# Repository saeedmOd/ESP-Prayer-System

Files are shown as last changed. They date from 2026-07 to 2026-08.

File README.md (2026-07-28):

# 🕌 ESP Prayer System

An advanced ESP-based Islamic prayer system using ESP8266/ESP32 with DFPlayer audio playback, MQTT control, OTA updates, and prayer time management.

---
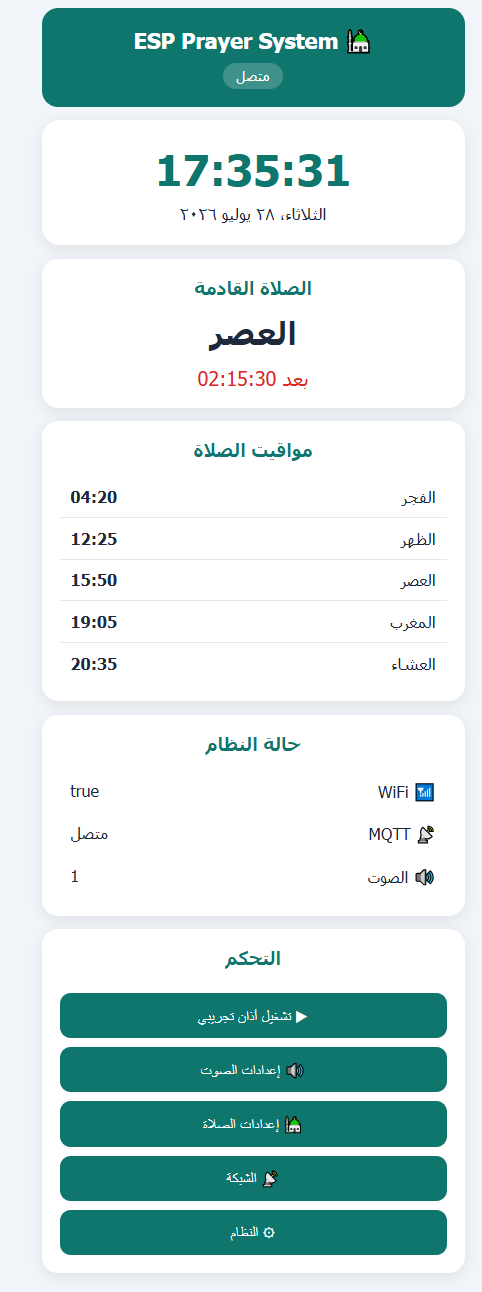
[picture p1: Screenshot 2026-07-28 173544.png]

# 📌 Project Overview

ESP Prayer System is a smart electronic device designed to:

- Calculate and manage prayer times.
- Play Azan automatically at prayer times.
- Control audio using DFPlayer Mini.
- Display prayer information on LCD/OLED screens.
- Support WiFi connectivity.
- Allow remote control using MQTT.
- Support OTA firmware updates.
- Store settings locally.

The system is designed with a modular software architecture using PlatformIO.

---

# ⚙️ Features

## 🕌 Prayer Management

- Automatic prayer time calculation.
- Next prayer countdown.
- Prayer schedule management.
- Support for different calculation methods.
- Daily prayer updates.

---

## 🔊 Audio System

Hardware:

- DFPlayer Mini MP3 Module
- Micro SD Card
- Amplifier (optional)

Supported audio:

The DFPlayer is controlled through UART communication.

---

# 📡 Connectivity

## WiFi

The system supports:

- WiFi connection.
- Automatic reconnect.
- Network status monitoring.

## MQTT

MQTT allows integration with:

- Home Assistant
- Node-RED
- Other IoT systems

Example:

---

# 🔄 OTA Update

The firmware supports Over-The-Air updates.

Advantages:

- No USB cable required.
- Update firmware remotely.
- Faster development.

Module:

---

# 📺 Display

Supported displays:

- OLED I2C
- LCD I2C

Information displayed:

- Current time
- Current date
- Next prayer
- Countdown timer
- System status

---

# 🏗️ Software Structure

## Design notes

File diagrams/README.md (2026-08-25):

# ESP Prayer System - Diagrams

## Overview

This folder contains system diagrams for the ESP Prayer System project, created using [Mermaid.js](https://mermaid.js.org/) syntax.

## Files

| File | Description |
|---|---|
| `block-diagram.md` | System architecture showing all components and their relationships |
| `system-flow.md` | Initialization flow, main loop, prayer detection, and menu state machine |
| `connection-map.md` | Complete wiring diagram, pin assignments, and power distribution |

## How to View

### Option 1: Mermaid Live Editor (Recommended)

1. Open [mermaid.live](https://mermaid.live)
2. Copy the code block from any `.md` file (between the ` ```mermaid ` and ` ``` ` markers)
3. Paste into the editor
4. The diagram will render automatically
5. Use the **Actions** menu to download as PNG, SVG, or PDF

### Option 2: VS Code

Install the **Mermaid Preview** extension:
1. Open VS Code Extensions (Ctrl+Shift+X)
2. Search for "Mermaid Preview"
3. Install the extension
4. Open any `.md` file
5. Click the preview icon (top-right corner)
6. Select "Mermaid" preview

### Option 3: GitHub/GitLab

These platforms render Mermaid diagrams natively in Markdown files. Simply push the files to your repository.

### Option 4: Command Line

```bash
# Install mermaid-cli
npm install -g @mermaid-js/mermaid-cli

# Generate PNG from mermaid file
mmdc -i block-diagram.md -o block-diagram.png
```

## Diagram Descriptions

### Block Diagram
Shows the complete system architecture:
- **ESP8266 NodeMCU** as the central controller
- Input devices (Rotary Encoder, Stop Button)
- Output devices (LCD, DFPlayer Mini, Speaker, Buzzer)
- Network services (WiFi, NTP, MQTT, OTA, Web Server)
- Software modules and their interactions

### System Flow
Four detailed flowcharts:
1. **Initialization Flow** - Step-by-step startup sequence
2. **Main Loop Flow** - Continuous operation cycle
3. **Prayer Detection Flow** - How prayer times trigger Azan/Iqama
4. **Rotary Menu State Machine** - UI navigation states

### Connection Map
Complete wiring reference:
- Visual wiring diagram with all connections
- Pin assignment table with GPIO mapping
- Power distribution diagram
- I2C bus and Software Serial details

## Component Summary

| Component | Interface | Pins Used |
|---|---|---|
| LCD 16x2 I2C | I2C | D1 (SCL), D2 (SDA) |
| DFPlayer Mini | UART (Software) | D5 (RX), D6 (TX) |
| Rotary Encoder | Digital | D7 (CLK), D8 (DT), D4 (SW) |
| Stop Button | Digital | D2 (shared with LCD SDA) |
| Buzzer | PWM | D3 |

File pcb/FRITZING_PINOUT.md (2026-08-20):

# ESP Prayer System - Quick Pinout Reference

## ESP8266 NodeMCU Pin Mapping

```
        ┌─────────────────────────────────────┐
        │           ESP8266 NodeMCU            │
        │                                      │
   3V3 ─┤ 3V3                          GND ├── GND
        │                                      │
   D0   ┤ GPIO16  (Not used)           A0   ├── ADC
        │                                      │
   D1   ┤ GPIO5   ──── LCD SCL               │
        │                                      │
   D2   ┤ GPIO4   ──── LCD SDA               │
        │              ──── Stop Button       │
        │                                      │
   D3   ┤ GPIO0   ──── Buzzer                │
        │                                      │
   D4   ┤ GPIO2   ──── Rotary SW             │
        │                                      │
   D5   ┤ GPIO14  ──── DFPlayer RX           │
        │                                      │
   D6   ┤ GPIO12  ──── DFPlayer TX           │
        │                                      │
   D7   ┤ GPIO13  ──── Rotary CLK            │
        │                                      │
   D8   ┤ GPIO15  ──── Rotary DT             │
        │                                      │
   RX   ┤ GPIO3   (Serial)           TX  ├── GPIO1
        │                                      │
        └─────────────────────────────────────┘
```

---

## Color Code

| Color | Purpose |
|---|---|
| 🔴 Red | Power (3V3, 5V) |
| ⚫ Black | Ground (GND) |
| 🔵 Blue | I2C Data (SDA) |
| 🟡 Yellow | I2C Clock (SCL) |
| 🟢 Green | Serial/UART |
| 🟠 Orange | Digital/Analog |
| 🟣 Purple | Control signals |

---

## Wire List (Copy-Paste Ready)

```
LCD I2C:
  VCC → 3V3
  GND → GND
  SDA → D2
  SCL → D1

DFPlayer Mini:
  VCC → 5V (or external)
  GND → GND
  RX  → D5 (via 1kΩ)
  TX  → D6

Rotary Encoder:
  VCC → 3V3
  GND → GND
  CLK → D7
  DT  → D8
  SW  → D4

Stop Button:
  Pin1 → D2
  Pin2 → GND

Buzzer:
  (+) → D3
  (-) → GND
```

---

## Quick ASCII Circuit

```
[USB/5V]───┐
           │
      ┌────┴────┐
      │ ESP8266 │
      │ NodeMCU │
      └────┬────┘
           │
    ┌──────┼──────┬──────────┬──────────┐
    │      │      │          │          │
┌───┴───┐ ┌┴────┐ ┌─────┐ ┌─┴───┐ ┌───┴───┐
│  LCD  │ │DFP  │ │ROTY │ │STOP │ │BUZZER │
│ 16x2  │ │Mini │ │Enc  │ │ BTN │ │       │
└───────┘ └─────┘ └─────┘ └─────┘ └───────┘
```

---

*For detailed wiring, see FRITZING_WIRING_GUIDE.md*

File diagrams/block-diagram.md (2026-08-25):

# ESP Prayer System - Block Diagram

```mermaid
graph TB
    subgraph "Power Supply"
        USB["USB / 5V Power"]
    end

    subgraph "ESP8266 NodeMCU"
        MCU["ESP8266<br/>NodeMCU"]
        CPU["CPU 80MHz<br/>RAM 80KB<br/>Flash 4MB"]
        WiFi_Mod["WiFi 2.4GHz<br/>802.11 b/g/n"]
        GPIO["GPIO Pins<br/>D0 - D8"]
    end

    subgraph "Input Devices"
        ROTARY["Rotary Encoder<br/>CLK=D7, DT=D8, SW=D4"]
        STOP["Stop Button<br/>D2"]
    end

    subgraph "Output Devices"
        LCD["LCD 16x2 I2C<br/>Address: 0x27<br/>SDA=D2, SCL=D1"]
        DFPlayer["DFPlayer Mini<br/>MP3 Module<br/>RX=D5, TX=D6"]
        SPEAKER["Speaker<br/>3W / 8Ohm"]
        BUZZER["Buzzer<br/>Active Piezo<br/>D3"]
    end

    subgraph "Network Services"
        NTP["NTP Client<br/>pool.ntp.org"]
        MQTT["MQTT Client<br/>PubSubClient"]
        OTA["OTA Updates<br/>ArduinoOTA"]
        WEB["Web Server<br/>AsyncWebServer<br/>Port 80"]
    end

    subgraph "Software Modules"
        STORAGE["Storage<br/>LittleFS<br/>config.json"]
        SETTINGS["Settings<br/>SystemSettings"]
        PRAYER["Prayer Engine<br/>6 Prayers<br/>8 Methods"]
        TIME["Time Manager<br/>NTP Sync"]
        MENU["Rotary Menu<br/>5 Modes"]
        DISPLAY_MOD["Display Manager<br/>LCD Driver"]
        CMD["Command Handler<br/>Serial/MQTT"]
    end

    subgraph "User Interface"
        BROWSER["Web Browser<br/>Dashboard"]
        LCD_UI["LCD Display<br/>Time + Prayer"]
        PHYSICAL["Physical Controls<br/>Rotary + Button"]
    end

    %% Power connections
    USB --> MCU

    %% MCU connections
    MCU --> CPU
    MCU --> WiFi_Mod
    MCU --> GPIO

    %% Input devices
    GPIO --> ROTARY
    GPIO --> STOP

    %% Output devices
    GPIO --> LCD
    GPIO --> DFPlayer
    DFPlayer --> SPEAKER
    GPIO --> BUZZER

    %% Network
    WiFi_Mod --> NTP
    WiFi_Mod --> MQTT
    WiFi_Mod --> OTA
    WiFi_Mod --> WEB

    %% Software modules
    MCU --> STORAGE
    MCU --> SETTINGS
    MCU --> PRAYER
    MCU --> TIME
    MCU --> MENU
    MCU --> DISPLAY_MOD
    MCU --> CMD

    %% User interfaces
    WEB --> BROWSER
    LCD --> LCD_UI
    ROTARY --> PHYSICAL
    STOP --> PHYSICAL

    %% Data flow
    TIME --> PRAYER
    PRAYER --> DISPLAY_MOD
    PRAYER --> DFPlayer
    PRAYER --> BUZZER
    SETTINGS --> PRAYER
    SETTINGS --> DISPLAY_MOD
    STORAGE --> SETTINGS
    MENU --> DISPLAY_MOD
    CMD --> PRAYER

    %% Styling
    classDef mcu fill:#e1f5fe,stroke:#0288d1,stroke-width:3px
    classDef input fill:#fff3e0,stroke:#f57c00,stroke-width:2px
    classDef output fill:#e8f5e9,stroke:#388e3c,stroke-width:2px
    classDef network fill:#f3e5f5,stroke:#7b1fa2,stroke-width:2px
    classDef software fill:#fce4ec,stroke:#c62828,stroke-width:2px
    classDef ui fill:#e0f2f1,stroke:#00695c,stroke-width:2px
    classDef power fill:#fffde7,stroke:#f9a825,stroke-width:2px

    class MCU,CPU,WiFi_Mod,GPIO mcu
    class ROTARY,STOP input
    class LCD,DFPlayer,SPEAKER,BUZZER output
    class NTP,MQTT,OTA,WEB network
    class STORAGE,SETTINGS,PRAYER,TIME,MENU,DISPLAY_MOD,CMD software
    class BROWSER,LCD_UI,PHYSICAL ui
    class USB power
```

---

## Legend

| Color | Category |
|---|---|
| 🔵 Blue | ESP8266 MCU (Central Controller) |
| 🟠 Orange | Input Devices |
| 🟢 Green | Output Devices |
| 🟣 Purple | Network Services |
| 🔴 Red | Software Modules |
| 🟤 Teal | User Interfaces |
| 🟡 Yellow | Power Supply |

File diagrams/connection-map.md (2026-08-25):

# ESP Prayer System - Connection Map

## 1. Complete Wiring Diagram

```mermaid
graph LR
    subgraph "ESP8266 NodeMCU"
        D0["D0<br/>GPIO16"]
        D1["D1<br/>GPIO5"]
        D2["D2<br/>GPIO4"]
        D3["D3<br/>GPIO0"]
        D4["D4<br/>GPIO2"]
        D5["D5<br/>GPIO14"]
        D6["D6<br/>GPIO12"]
        D7["D7<br/>GPIO13"]
        D8["D8<br/>GPIO15"]
        VCC["3V3"]
        GND1["GND"]
        VIN["VIN/5V"]
        GND2["GND"]
    end

    subgraph "LCD 16x2 I2C"
        LCD_VCC["VCC"]
        LCD_GND["GND"]
        LCD_SDA["SDA"]
        LCD_SCL["SCL"]
    end

    subgraph "DFPlayer Mini"
        DFP_VCC["VCC"]
        DFP_GND["GND"]
        DFP_RX["RX"]
        DFP_TX["TX"]
        DFP_SPK1["SPK_1"]
        DFP_SPK2["SPK_2"]
    end

    subgraph "Rotary Encoder"
        ROT_VCC["VCC"]
        ROT_GND["GND"]
        ROT_CLK["CLK"]
        ROT_DT["DT"]
        ROT_SW["SW"]
    end

    subgraph "Stop Button"
        BTN_1["Pin 1"]
        BTN_2["Pin 2"]
    end

    subgraph "Buzzer"
        BUZ_PLUS["+"]
        BUZ_MINUS["-"]
    end

    subgraph "Speaker"
        SPK_1["+"]
        SPK_2["-"]
    end

    %% LCD Connections
    D1 -->|"SCL"| LCD_SCL
    D2 -->|"SDA"| LCD_SDA
    VCC --> LCD_VCC
    GND1 --> LCD_GND

    %% DFPlayer Connections
    D5 -->|"RX (via 1kΩ)"| DFP_RX
    D6 -->|"TX"| DFP_TX
    VIN --> DFP_VCC
    GND2 --> DFP_GND
    DFP_SPK1 --> SPK_1
    DFP_SPK2 --> SPK_2

    %% Rotary Encoder Connections
    D7 --> ROT_CLK
    D8 --> ROT_DT
    D4 --> ROT_SW
    VCC --> ROT_VCC
    GND1 --> ROT_GND

    %% Stop Button
    D2 --> BTN_1
    GND1 --> BTN_2

    %% Buzzer
    D3 --> BUZ_PLUS
    GND1 --> BUZ_MINUS

    style D1 fill:#4caf50,color:#fff
    style D2 fill:#4caf50,color:#fff
    style D3 fill:#ff5722,color:#fff
    style D4 fill:#ff9800,color:#fff
    style D5 fill:#2196f3,color:#fff
    style D6 fill:#2196f3,color:#fff
    style D7 fill:#ff9800,color:#fff
    style D8 fill:#ff9800,color:#fff
```

## 2. Pin Assignment Table

| Pin | GPIO | Component | Function | Wire Color |
|-----|---|---|---|---|
| D0 | GPIO16 | - | Not Used | - |
| **D1** | GPIO5 | LCD 16x2 | I2C SCL | 🟡 Yellow |
| **D2** | GPIO4 | LCD 16x2 | I2C SDA | 🔵 Blue |
| **D2** | GPIO4 | Stop Button | Digital Input | 🟣 Purple |
| **D3** | GPIO0 | Buzzer | PWM Output | 🟠 Orange |
| **D4** | GPIO2 | Rotary Encoder | SW (Button) | 🟠 Orange |
| **D5** | GPIO14 | DFPlayer Mini | RX (via 1kΩ) | 🟢 Green |
| **D6** | GPIO12 | DFPlayer Mini | TX | 🟢 Green |
| **D7** | GPIO13 | Rotary Encoder | CLK | 🟠 Orange |
| **D8** | GPIO15 | Rotary Encoder | DT | 🟠 Orange |
| RX | GPIO3 | Serial Monitor | Debug Output | - |
| TX | GPIO1 | Serial Monitor | Debug Input | - |
| 3V3 | - | LCD, Rotary | Power (3.3V) | 🔴 Red |
| VIN | - | DFPlayer | Power (5V) | 🔴 Red |
| GND | - | All Components | Ground | ⚫ Black |

## 3. Power Distribution

```mermaid
graph TD
    USB["USB / 5V Source"] --> VIN["VIN Pin<br/>5V"]

    VIN --> DFP_PWR["DFPlayer Mini<br/>VCC (5V)"]
    VIN --> REG["3.3V Regulator<br/>(On-board)"]

    REG --> VCC33["3V3 Pin<br/>3.3V"]
    VCC33 --> LCD_PWR["LCD 16x2<br/>VCC"]
    VCC33 --> ROT_PWR["Rotary Encoder<br/>VCC"]

    USB --> GND_BUS["Common Ground"]
    GND_BUS --> DFP_GND["DFPlayer<br/>GND"]
    GND_BUS --> LCD_GND["LCD<br/>GND"]
    GND_BUS --> ROT_GND["Rotary<br/>GND"]
    GND_BUS --> BTN_GND["Stop Button<br/>GND"]
    GND_BUS --> BUZ_GND["Buzzer<br/>GND"]

    style USB fill:#ff9800,color:#fff
    style REG fill:#4caf50,color:#fff
    style GND_BUS fill:#333,color:#fff
```

## 4. I2C Bus

```mermaid
graph LR
    SDA["SDA Bus<br/>GPIO4 / D2"] --> LCD["LCD 16x2<br/>Address: 0x27"]
    SCL["SCL Bus<br/>GPIO5 / D1"] --> LCD

    style SDA fill:#2196f3,color:#fff
    style SCL fill:#ffc107,color:#000
```

## 5. Software Serial (DFPlayer)

```mermaid
graph LR
    ESP_TX["ESP TX<br/>GPIO14 / D5"] -->|"via 1kΩ"| DFP_RX["DFPlayer RX"]
    DFP_TX["DFPlayer TX"] --> ESP_RX["ESP RX<br/>GPIO12 / D6"]

    style ESP_TX fill:#4caf50,color:#fff
    style DFP_RX fill:#2196f3,color:#fff
    style DFP_TX fill:#2196f3,color:#fff
    style ESP_RX fill:#4caf50,color:#fff

    note1["Baud Rate: 9600"]
    note2["Voltage: 3.3V Logic"]
```

---

## Quick Reference

```
┌─────────────────────────────────────────────────┐
│              ESP8266 NodeMCU                    │
│                                                 │
│  3V3 ──┬──┬────────────────────── GND ──┬──┬──  │
│        │  │                             │  │    │
│  D0    │  │ (Not Used)            A0    │  │    │
│        │  │                             │  │    │
│  D1 ───┼──┼──── LCD SCL                 │  │    │
│        │  │                             │  │    │
│  D2 ───┼──┼──── LCD SDA                 │  │    │
│        │  │     Stop Button             │  │    │
│        │  │                             │  │    │
│  D3 ───┼──┼──── Buzzer (+)              │  │    │
│        │  │                             │  │    │
│  D4 ───┼──┼──── Rotary SW               │  │    │
│        │  │                             │  │    │
│  D5 ───┼──┼──── DFPlayer RX (1kΩ)       │  │    │
│        │  │                             │  │    │
│  D6 ───┼──┼──── DFPlayer TX             │  │    │
│        │  │                             │  │    │
│  D7 ───┼──┼──── Rotary CLK              │  │    │
│        │  │                             │  │    │
│  D8 ───┼──┼──── Rotary DT               │  │    │
│        │  │                             │  │    │
│  RX    │  │ (Serial Debug)         TX   │  │    │
│        │  │                             │  │    │
└────────┴──┴─────────────────────────────┴──┴──┘
         │  │                             │  │
         │  └──── 3.3V Power ────────────┘  │
         └──── 5V (VIN) ────────────────────┘
```

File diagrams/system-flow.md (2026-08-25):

# ESP Prayer System - System Flow Diagram

## 1. Initialization Flow (setup)

```mermaid
flowchart TD
    START["🔌 Power On / Reset"] --> SERIAL["Initialize Serial<br/>115200 baud"]
    SERIAL --> VERSION["Print Version Info<br/>v1.0.0"]
    VERSION --> STORAGE["Mount LittleFS<br/>Load config.json"]
    STORAGE --> SETTINGS["Load Settings<br/>Validate & Clamp"]
    SETTINGS --> WIFI{"WiFi Connected?"}

    WIFI -->|"Yes (STA Mode)"| IP["Get IP Address"]
    WIFI -->|"No / Timeout"| AP["Start AP Mode<br/>ESP-Prayer-Setup<br/>192.168.4.1"]

    IP --> WEB["Start Web Server<br/>Port 80"]
    AP --> WEB

    WEB --> NET_CHECK{"WiFi Connected?"}

    NET_CHECK -->|"Yes"| NET_INIT["Initialize Network Services"]
    NET_CHECK -->|"No"| HW_INIT

    NET_INIT --> OTA["OTA Ready<br/>ArduinoOTA"]
    OTA --> NTP["NTP Sync<br/>pool.ntp.org"]
    NTP --> TIME_OK{"Time Synced?"}

    TIME_OK -->|"Yes"| MQTT["MQTT Init<br/>Connect Broker"]
    TIME_OK -->|"No"| HW_INIT

    MQTT --> DFP["DFPlayer Init<br/>9600 baud"]
    DFP --> PRAYER["Prayer Init<br/>Calculate Times"]
    PRAYER --> DISP["Display Init<br/>LCD 16x2"]
    DISP --> MARK["Mark Network<br/>Services Ready"]

    MARK --> HW_INIT["Hardware Init<br/>Buzzer + Rotary"]
    HW_INIT --> TONE["Play Startup Tone"]
    TONE --> WIFI_TONE{"WiFi Connected?"}
    WIFI_TONE -->|"Yes"| CONN_TONE["Play WiFi Connected Tone"]
    WIFI_TONE -->|"No"| MENU_INIT
    CONN_TONE --> MENU_INIT["Rotary Menu Init"]
    MENU_INIT --> READY["✅ System Ready"]

    style START fill:#ff9800,color:#fff
    style READY fill:#4caf50,color:#fff
    style WIFI fill:#2196f3,color:#fff
    style NET_CHECK fill:#2196f3,color:#fff
    style TIME_OK fill:#2196f3,color:#fff
    style WIFI_TONE fill:#2196f3,color:#fff
```

## 2. Main Loop Flow

```mermaid
flowchart TD
    LOOP["🔄 Main Loop Start"] --> HW["hardware_loop()<br/>Read Encoder + Button<br/>Update Buzzer Tones"]
    HW --> WIFI_L["wifi_loop()<br/>Monitor Connection<br/>Reconnect if Needed"]

    WIFI_L --> WIFI_OK{"WiFi Connected?"}

    WIFI_OK -->|"Yes"| NET_CHECK{"Network<br/>Initialized?"}
    WIFI_OK -->|"No"| PRAYER_L

    NET_CHECK -->|"Yes"| OTA_H["OTA.handle()<br/>Process Updates"]
    NET_CHECK -->|"No"| TRY_INIT["Try Initialize<br/>Network Services"]

    OTA_H --> MQTT_L["mqtt_loop()<br/>Process Messages"]
    MQTT_L --> TIME_U["time_update()<br/>Refresh NTP Time"]

    TRY_INIT --> PRAYER_L
    TIME_U --> PRAYER_L

    PRAYER_L["prayer_loop()<br/>Check Prayer Times<br/>Trigger Azan/Iqama"]

    PRAYER_L --> MENU_L{"Network<br/>Initialized?"}
    MENU_L -->|"Yes"| RMENU["rotary_menu_loop()<br/>Process Input<br/>Update Display"]
    MENU_L -->|"No"| WEB_L

    RMENU --> WEB_L["web_server_loop()<br/>Handle HTTP Requests"]
    WEB_L --> LOOP

    style LOOP fill:#ff9800,color:#fff
    style WIFI_OK fill:#2196f3,color:#fff
    style NET_CHECK fill:#2196f3,color:#fff
    style MENU_L fill:#2196f3,color:#fff
```

## 3. Prayer Time Detection Flow

```mermaid
flowchart TD
    CHECK["prayer_loop()"] --> TIME{"Time Changed?"}

    TIME -->|"No"| SKIP["Skip"]
    TIME -->|"Yes"| DAY{"New Day?"}

    DAY -->|"Yes"| RECALC["Recalculate<br/>All Prayer Times"]
    DAY -->|"No"| FAJR{"Fajr Time?"}

    RECALC --> FAJR

    FAJR -->|"Yes & Not Played"| PLAY_AZAN_F["Play Azan<br/>Fajr"]
    FAJR -->|"No"| DHUHR{"Dhuhr Time?"}

    PLAY_AZAN_F --> IQAMA_F{"Iqama<br/>Delay Done?"}
    IQAMA_F -->|"Yes"| PLAY_IQAMA_F["Play Iqama<br/>Fajr"]

    DHUHR -->|"Yes & Not Played"| PLAY_AZAN_D["Play Azan<br/>Dhuhr"]
    DHUHR -->|"No"| ASR{"Asr Time?"}

    PLAY_AZAN_D --> IQAMA_D{"Iqama<br/>Delay Done?"}
    IQAMA_D -->|"Yes"| PLAY_IQAMA_D["Play Iqama<br/>Dhuhr"]

    ASR -->|"Yes & Not Played"| PLAY_AZAN_A["Play Azan<br/>Asr"]
    ASR -->|"No"| MAGHRIB{"Maghrib Time?"}

    PLAY_AZAN_A --> IQAMA_A{"Iqama<br/>Delay Done?"}
    IQAMA_A -->|"Yes"| PLAY_IQAMA_A["Play Iqama<br/>Asr"]

    MAGHRIB -->|"Yes & Not Played"| PLAY_AZAN_M["Play Azan<br/>Maghrib"]
    MAGHRIB -->|"No"| ISHA{"Isha Time?"}

    PLAY_AZAN_M --> IQAMA_M{"Iqama<br/>Delay Done?"}
    IQAMA_M -->|"Yes"| PLAY_IQAMA_M["Play Iqama<br/>Maghrib"]

    ISHA -->|"Yes & Not Played"| PLAY_AZAN_I["Play Azan<br/>Isha"]
    ISHA -->|"No"| ADHKAR

    PLAY_AZAN_I --> IQAMA_I{"Iqama<br/>Delay Done?"}
    IQAMA_I -->|"Yes"| PLAY_IQAMA_I["Play Iqama<br/>Isha"]

    ADHKAR["Check Adhkar<br/>(Morning/Evening)"] --> KAHF{"Friday?<br/>Al-Kahf Time?"}
    KAHF -->|"Yes"| PLAY_KAHF["Play Surah<br/>Al-Kahf"]
    KAHF -->|"No"| CUSTOM{"Custom Alert<br/>Time?"}
    CUSTOM -->|"Yes"| PLAY_CUSTOM["Play Custom<br/>Alert"]
    CUSTOM -->|"No"| SKIP

    PLAY_IQAMA_F --> SKIP
    PLAY_IQAMA_D --> SKIP
    PLAY_IQAMA_A --> SKIP
    PLAY_IQAMA_M --> SKIP
    PLAY_IQAMA_I --> SKIP
    PLAY_KAHF --> SKIP
    PLAY_CUSTOM --> SKIP

    style CHECK fill:#ff9800,color:#fff
    style TIME fill:#2196f3,color:#fff
    style DAY fill:#2196f3,color:#fff
```

## 4. Rotary Menu State Machine

```mermaid
stateDiagram-v2
    [*] --> MODE_CLOCK: Init

    MODE_CLOCK --> MODE_MENU: Long Press
    MODE_CLOCK --> MODE_CLOCK: Short Press (Mute/Unmute)
    MODE_CLOCK --> MODE_CLOCK: Rotate (Volume +/-)

    MODE_MENU --> MODE_PRAYERS: Select "Prayer Times"
    MODE_MENU --> MODE_VOLUME: Select "Volume"
    MODE_MENU --> MODE_BRIGHTNESS: Select "Brightness"
    MODE_MENU --> MODE_CLOCK: Back (Long Press)

    MODE_PRAYERS --> MODE_CLOCK: Back
    MODE_PRAYERS --> MODE_PRAYERS: Browse (Rotate)

    MODE_VOLUME --> MODE_CLOCK: Back
    MODE_VOLUME --> MODE_VOLUME: Adjust (Rotate)

    MODE_BRIGHTNESS --> MODE_CLOCK: Back
    MODE_BRIGHTNESS --> MODE_BRIGHTNESS: Toggle (Press)

    note right of MODE_CLOCK
        Default Mode
        Shows: Time + Next Prayer
        Rotary: Volume Control
        Press: Mute/Unmute
    end note
```

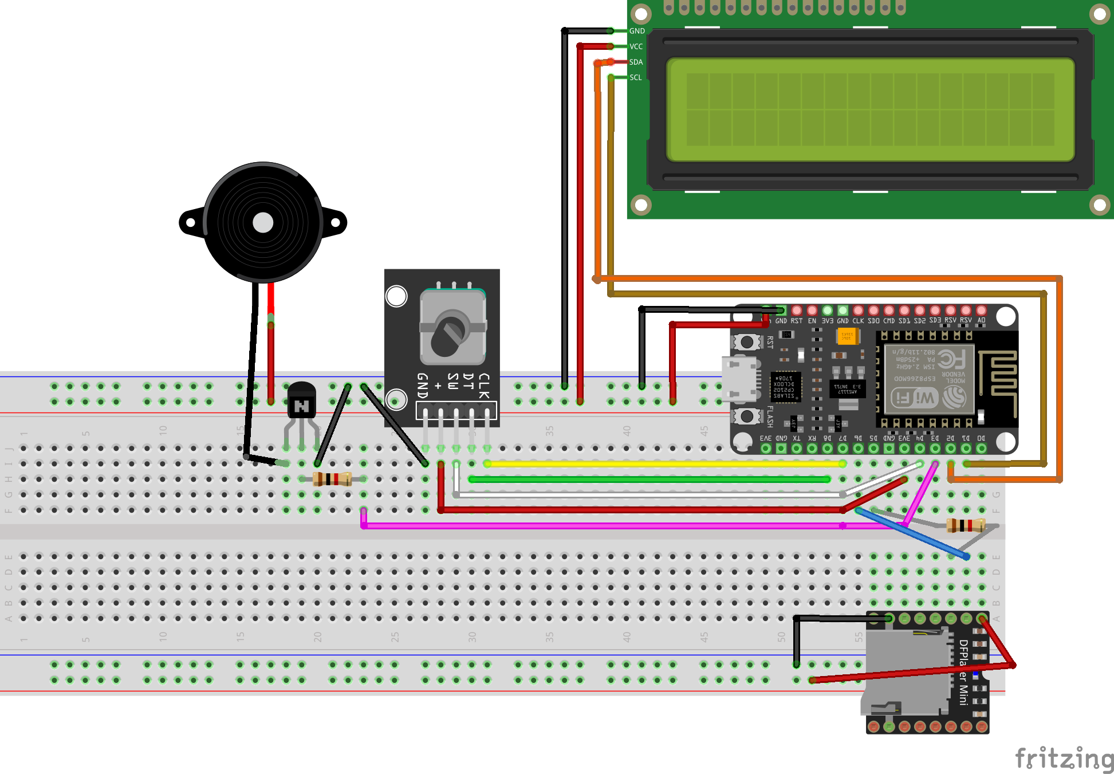
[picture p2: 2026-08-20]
pcb/ESP-Prayer-System_bb.png

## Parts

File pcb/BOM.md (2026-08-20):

# ESP Prayer System - Bill of Materials (BOM)

## Required Components

| #  | Reference | Component | Value/Package | Qty | Notes |
|----|---|---|---|-----|---|
| 1  | U1 | ESP8266 NodeMCU | 12-pin headers | 1 | V3 or Lite version |
| 2  | LCD1 | LCD 16x2 I2C Module | 0x27 address | 1 | With I2C backpack |
| 3  | DF1 | DFPlayer Mini | MP3 Module | 1 | With micro SD card slot |
| 4  | ENC1 | Rotary Encoder | KY-040 | 1 | With push button |
| 5  | SW1 | Stop Button | 6x6mm tactile | 1 | Normally Open |
| 6  | BZ1 | Active Buzzer | 5V, 5mm | 1 | Self-driving type |
| 7  | Q1 | NPN Transistor | 2N2222/S8050 | 1 | TO-92 package |
| 8  | R1 | Resistor | 1kΩ, 1/4W | 1 | Base resistor for transistor |
| 9  | R2 | Resistor | 1kΩ, 1/4W | 1 | DFPlayer RX line protection |

## Passive Components

| #  | Reference | Component | Value | Package | Qty | Notes |
|----|---|---|---|---|-----|---|
| 10 | C1 | Ceramic Capacitor| 100nF | 0805 | 1 | DFPlayer power filter  |
| 11 | C2 | Electrolytic Cap  | 100µF/10V | Radial  | 1 | Main power filter |
| 12 | C3 | Ceramic Capacitor| 100nF | 0805 | 1 | Rotary encoder debounce|

## Connectors

| #  | Reference  | Component | Pins | Qty | Notes |
|----|---|---|---|-----|---|
| 13 | J1 | USB Micro/B Type-B  | - | 1 | Power input (on NodeMCU) |
| 14 | J2 | Pin Header 2.54mm | 4pin | 1 | LCD I2C connection |
| 15 | J3 | Pin Header 2.54mm | 4pin | 1 | DFPlayer connection |
| 16 | J4 | Pin Header 2.54mm | 5pin | 1 | Rotary Encoder |
| 17 | J5 | Pin Header 2.54mm | 2pin | 1 | Stop Button |
| 18 | J6 | Pin Header 2.54mm | 2pin | 1 | Buzzer |
| 19 | J7 | Screw Terminal 3.5mm| 2pin | 1 | Speaker output (optional)|

## Optional Components

| #  | Reference | Component | Value | Qty | Notes |
|----|---|---|---|-----|---|
| 20 | LED1 | LED | Green | 1 | Power indicator |
| 21 | R3 | Resistor | 470Ω | 1 | LED current limiter |
| 22 | C4 | Ceramic Capacitor | 10µF | 1 | Optional power filtering |

## Mechanical

| #  | Component | Specification | Qty | Notes |
|----|---|---|-----|---|
| 23 | PCB | 80x50mm, 2L | 1 | FR4, 1.6mm thick |
| 24 | Mounting Hardware| M3 screws | 4 | For enclosure |
| 25 | Rubber Feet | 8mm diameter  | 4 | Non-slip |

---

## Source Links (Examples)

| Component | Search Term |
|---|---|
| ESP8266 | "NodeMCU ESP8266 V3" |
| LCD I2C | "LCD 1602 I2C 0x27" |
| DFPlayer Mini | "DFPlayer Mini MP3 Module" |
| Rotary Encoder  | "KY-040 Rotary Encoder" |
| Active Buzzer | "Active Buzzer 5V 5mm" |
| 2N2222 | "2N2222 NPN Transistor" |
| 1kΩ Resistors | "1kohm 1/4W Resistor Pack" |
| 100nF Caps | "100nF 0805 Capacitor Pack"  |
| 100µF Cap | "100uF 10V Electrolytic" |

---

## Estimated Cost

| Category | Estimated Cost (USD) |
|---|---|
| ESP8266 | $3 - $5 |
| LCD I2C | $2 - $3 |
| DFPlayer Mini  | $2 - $4 |
| Rotary Encoder | $1 - $2 |
| Passive Parts  | $1 - $2 |
| Connectors | $1 - $2 |
| PCB (5 pcs) | $5 - $10 |
| **Total** | **$15 - $28** |

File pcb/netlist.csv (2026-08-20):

Component | Reference | Pin | Net
ESP8266 NodeMCU | U1 | D0/GPIO16 | STOP_BTN
ESP8266 NodeMCU | U1 | D1/GPIO5 | LCD_SCL
ESP8266 NodeMCU | U1 | D2/GPIO4 | LCD_SDA
ESP8266 NodeMCU | U1 | D3/GPIO0 | BUZZER_DRIVE
ESP8266 NodeMCU | U1 | D4/GPIO2 | ROTARY_SW
ESP8266 NodeMCU | U1 | D5/GPIO14 | DFPLAYER_TX
ESP8266 NodeMCU | U1 | D6/GPIO12 | DFPLAYER_RX
ESP8266 NodeMCU | U1 | D7/GPIO13 | ROTARY_CLK
ESP8266 NodeMCU | U1 | D8/GPIO15 | ROTARY_DT
ESP8266 NodeMCU | U1 | 3V3 | +3V3
ESP8266 NodeMCU | U1 | GND | GND
ESP8266 NodeMCU | U1 | VIN | +5V
LCD 16x2 I2C | LCD1 | GND | GND
LCD 16x2 I2C | LCD1 | VCC | +5V
LCD 16x2 I2C | LCD1 | SDA | LCD_SDA
LCD 16x2 I2C | LCD1 | SCL | LCD_SCL
DFPlayer Mini | DF1 | VCC | +5V
DFPlayer Mini | DF1 | GND | GND
DFPlayer Mini | DF1 | RX | DFPLAYER_RX
DFPlayer Mini | DF1 | TX | DFPLAYER_TX
DFPlayer Mini | DF1 | SP+ | SPK_P
DFPlayer Mini | DF1 | SP- | SPK_N
Rotary Encoder | ENC1 | CLK | ROTARY_CLK
Rotary Encoder | ENC1 | DT | ROTARY_DT
Rotary Encoder | ENC1 | SW | ROTARY_SW
Rotary Encoder | ENC1 | + | +3V3
Rotary Encoder | ENC1 | - | GND
Stop Button | SW1 | Pin1 | STOP_BTN
Stop Button | SW1 | Pin2 | GND
Resistor | R1 | Pin1 | BUZZER_DRIVE
Resistor | R1 | Pin2 | Q1_BASE
NPN Transistor | Q1 | Base | Q1_BASE
NPN Transistor | Q1 | Collector | BUZZER_COL
NPN Transistor | Q1 | Emitter | GND
Active Buzzer | BZ1 | Pin1 | +5V
Active Buzzer | BZ1 | Pin2 | BUZZER_COL
Capacitor | C1 | Pin1 | +5V
Capacitor | C1 | Pin2 | GND
Capacitor | C2 | Pin1 | +5V
Capacitor | C2 | Pin2 | GND

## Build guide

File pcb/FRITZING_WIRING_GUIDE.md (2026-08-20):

# ESP Prayer System - Fritzing Wiring Guide

## Overview

This document provides complete wiring instructions for recreating the ESP Prayer System circuit in Fritzing.

---

## Pin Connection Table

| ESP8266 Pin | GPIO | Component | Component Pin | Wire Color (Suggested) |
|---|---|---|---|---|
| D1 | GPIO5 | LCD 16x2 I2C | SCL | Yellow |
| D2 | GPIO4 | LCD 16x2 I2C | SDA | Blue |
| D2 | GPIO4 | Stop Button | Pin 1 | Red |
| D3 | GPIO0 | Active Buzzer (+) | + | Orange |
| D4 | GPIO2 | Rotary Encoder | SW (Switch) | Purple |
| D5 | GPIO14 | DFPlayer Mini | RX | Green |
| D6 | GPIO12 | DFPlayer Mini | TX | White |
| D7 | GPIO13 | Rotary Encoder | CLK | Gray |
| D8 | GPIO15 | Rotary Encoder | DT | Brown |
| 3V3 | - | LCD 16x2 I2C | VCC | Red |
| 3V3 | - | Rotary Encoder | VCC (+) | Red |
| GND | - | All Components | GND | Black |
| GND | - | DFPlayer Mini | GND | Black |
| GND | - | LCD 16x2 I2C | GND | Black |
| GND | - | Rotary Encoder | GND (-) | Black |
| GND | - | Stop Button | Pin 2 | Black |

---

## Component Connections Detail

### 1. LCD 16x2 I2C Module

```
LCD I2C Module        ESP8266
─────────────        ───────
VCC  ──────────────── 3V3
GND  ──────────────── GND
SDA  ──────────────── D2 (GPIO4)
SCL  ──────────────── D1 (GPIO5)
```

**Note:** LCD address is 0x27 (default for most I2C backpacks)

---

### 2. DFPlayer Mini MP3 Module

```
DFPlayer Mini        ESP8266
─────────────        ───────
VCC  ──────────────── 5V (or external 5V)
GND  ──────────────── GND
RX   ──────────────── D5 (GPIO14) [via 1kΩ resistor]
TX   ──────────────── D6 (GPIO12)
BUSY ──────────────── (Not connected)
```

**Important Notes:**
- Add 1kΩ resistor between ESP8266 D5 and DFPlayer RX for line protection
- DFPlayer requires FAT32 formatted micro SD card
- Recommended: Use external 5V power for DFPlayer (not from ESP8266)
- Connect GND between DFPlayer and ESP8266 (common ground)

---

### 3. Rotary Encoder (KY-040)

```
Rotary Encoder       ESP8266
─────────────        ───────
VCC (+) ──────────── 3V3
GND (-) ──────────── GND
CLK    ──────────── D7 (GPIO13)
DT     ──────────── D8 (GPIO15)
SW     ──────────── D4 (GPIO2)
```

**Note:** The push button (SW) is used for menu navigation

---

### 4. Stop Button (Tactile 6x6mm)

```
Stop Button          ESP8266
─────────────        ───────
Pin 1  ──────────── D2 (GPIO4)
Pin 2  ──────────── GND
```

**Note:** Button is normally open, active LOW (internal pull-up enabled)

---

### 5. Active Buzzer

```
Buzzer               ESP8266
─────────────        ───────
(+)  ──────────────── D3 (GPIO0)
(-)  ──────────────── GND
```

**Note:** Active buzzer has built-in oscillator - just apply voltage to sound

---

## Power Distribution

### Option A: USB Power (Simple)

```
USB Power (5V)
    │
    ├── ESP8266 VIN
    │
    └── DFPlayer VCC (if powered from USB)
```

### Option B: External Power (Recommended)

```
External 5V Power Supply
    │
    ├── DFPlayer VCC
    │
    └── ESP8266 VIN (or USB)
```

**Important:** Always connect GND between all modules!

---

## Complete Wiring Diagram (ASCII)

```
                    ┌─────────────────┐
                    │   ESP8266       │
                    │   NodeMCU       │
                    │                 │
    LCD SCL ────────│ D1 (GPIO5)     │
    LCD SDA ────────│ D2 (GPIO4)     │──── Stop Button
    Buzzer  ────────│ D3 (GPIO0)     │
    Rotary SW ──────│ D4 (GPIO2)     │
    DFPlayer RX ────│ D5 (GPIO14)    │
    DFPlayer TX ────│ D6 (GPIO12)    │
    Rotary CLK ─────│ D7 (GPIO13)    │
    Rotary DT ──────│ D8 (GPIO15)    │
                    │                 │
    3V3 ────────────│ 3V3            │
    GND ────────────│ GND            │
                    └─────────────────┘
                           │
                    ┌──────┴──────┐
                    │             │
              ┌─────┴─────┐ ┌────┴────┐
              │   LCD     │ │ DFPlayer│
              │  16x2 I2C │ │  Mini   │
              └───────────┘ └─────────┘
```

---

## Fritzing Component Search Terms

| Component | Search Term in Fritzing |
|---|---|
| ESP8266 | "NodeMCU" or "ESP8266" |
| LCD I2C | "LCD 16x2 I2C" or "HD44780" |
| DFPlayer Mini | "DFPlayer Mini" or "MP3 Module" |
| Rotary Encoder | "KY-040" or "Rotary Encoder" |
| Active Buzzer | "Active Buzzer" |
| Tactile Button | "Tactile Button 6x6mm" |
| Resistors | "Resistor 1kΩ" |
| Capacitors | "Ceramic Capacitor 100nF" |

---

## Important Notes

### Pin Conflict Warning

**D2 (GPIO4) is shared between:**
- LCD I2C SDA
- Stop Button

This works because:
- LCD uses I2C protocol (only when communicating)
- Stop button is read via digitalRead (only when pressed)
- They don't conflict in normal operation

### GPIO Restrictions (ESP8266)

| GPIO | Notes |
|---|---|
| GPIO0 (D3) | Boot mode - ensure HIGH at boot |
| GPIO2 (D4) | Boot mode - must be HIGH at boot |
| GPIO15 (D8) | Must be LOW at boot (pulled down internally) |
| GPIO16 (D0) | No PWM, no interrupt support |

### Recommended Capacitors

Add these capacitors for stability:

1. **100nF ceramic** across DFPlayer VCC-GND (close to DFPlayer)
2. **100µF electrolytic** across main power rail
3. **100nF ceramic** across ESP8266 3V3-GND

---

## Assembly Order

1. Place ESP8266 NodeMCU on breadboard
2. Connect LCD I2C (4 wires: VCC, GND, SDA, SCL)
3. Connect Rotary Encoder (5 wires: VCC, GND, CLK, DT, SW)
4. Connect Stop Button (2 wires: D2, GND)
5. Connect Buzzer (2 wires: D3, GND)
6. Connect DFPlayer (4 wires: VCC, GND, RX, TX)
7. Add protection resistor (1kΩ) on DFPlayer RX line
8. Add filtering capacitors
9. Connect power and test

---

## Testing Checklist

- [ ] ESP8266 powers on (LED blinks)
- [ ] LCD displays "ESP Prayer"
- [ ] Rotary encoder scrolls menu
- [ ] Push button selects menu items
- [ ] Stop button stops audio
- [ ] Buzzer plays startup tone
- [ ] DFPlayer plays audio files
- [ ] WiFi connects successfully
- [ ] Web server accessible

---

## Troubleshooting

| Issue | Solution |
|---|---|
| LCD not displaying | Check I2C address (try 0x3F), check SDA/SCL swapped |
| DFPlayer not working | Check SD card (FAT32), check wiring, add 1kΩ resistor |
| Rotary not responding | Check CLK/DT not swapped, check VCC connected |
| Buzzer silent | Check polarity (+ to D3, - to GND) |
| WiFi not connecting | Check antenna, verify SSID/password in settings |

---

## Reference Images

- `Image_1.jpg` - Hardware photo
- `Image_2.jpg` - Hardware photo
- `Image_3.png` - Hardware photo
- `Image_4.png` - Hardware photo

---

*Generated for ESP Prayer System v1.0*
*Compatible with Fritzing 0.9.x and later*

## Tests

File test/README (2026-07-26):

# 🕌 ESP Prayer System

An advanced ESP-based Islamic prayer system using ESP8266/ESP32 with DFPlayer audio playback, MQTT control, OTA updates, and prayer time management.

---

# 📌 Project Overview

ESP Prayer System is a smart IoT prayer device designed to provide automatic Azan playback and prayer information display.

The system provides:

- Automatic prayer time management.
- Azan playback using DFPlayer Mini.
- LCD/OLED prayer information display.
- WiFi connectivity.
- MQTT remote control.
- OTA firmware updates.
- Local settings storage.

The firmware is developed using **PlatformIO** with a modular architecture for easy maintenance and future expansion.

---

# ⚙️ Features

## 🕌 Prayer Management

- Automatic prayer time calculation.
- Current prayer detection.
- Next prayer countdown.
- Daily prayer schedule.
- Prayer notifications.
- Configurable calculation settings.

---

# 🔊 Audio System

Hardware:

- DFPlayer Mini MP3 Module.
- Micro SD Card.
- Speaker / Amplifier.

The DFPlayer is controlled through UART communication.

## SD Card Structure

The audio files are organized as:

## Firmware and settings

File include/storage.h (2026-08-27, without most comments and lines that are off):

#pragma once
#include <Arduino.h>
#include <ArduinoJson.h>
#define STORAGE_CONFIG_FILE "/config.json"
#define STORAGE_TEMP_FILE "/config.tmp"
#define STORAGE_BACKUP_FILE "/config.bak"
#define STORAGE_VERSION "2.0"
#define STORAGE_CONFIG_VERSION 2
#define DEFAULT_DEVICE_NAME "ESP-Prayer-System"
#define DEFAULT_WIFI_ENABLE true
#define DEFAULT_WIFI_AUTO_RECONNECT true
#define DEFAULT_MQTT_ENABLE false
#define DEFAULT_MQTT_SERVER ""
#define DEFAULT_MQTT_PORT 1883
#define DEFAULT_MQTT_TOPIC "ESP-Prayer-System"
#define DEFAULT_OTA_ENABLE true
#define DEFAULT_CITY "Al Ain"
#define DEFAULT_COUNTRY "UAE"
#define DEFAULT_LATITUDE 24.2075f
#define DEFAULT_LONGITUDE 55.7447f
#define DEFAULT_TIMEZONE 4
#define DEFAULT_TIME_FORMAT "24H"
#define DEFAULT_CALCULATION_METHOD "UmmAlQura"
#define DEFAULT_ASR_METHOD "Shafii"
#define DEFAULT_HIGH_LATITUDE_RULE "AngleBased"
#define DEFAULT_FAJR_OFFSET 0
#define DEFAULT_DHUHR_OFFSET 0
#define DEFAULT_ASR_OFFSET 0
#define DEFAULT_MAGHRIB_OFFSET 0
#define DEFAULT_ISHA_OFFSET 0
#define DEFAULT_AUDIO_ENABLE true
#define DEFAULT_AZAN_ENABLE false
#define DEFAULT_AZAN_FOLDER 1
#define DEFAULT_AZAN_FILE 1
#define DEFAULT_SURAH_FOLDER 2
#define DEFAULT_SURAH_FILE 1
#define DEFAULT_SHORT_SURAH_FOLDER 3
#define DEFAULT_DUA_FOLDER 4
#define DEFAULT_DISPLAY_ENABLE true
#define DEFAULT_BRIGHTNESS 100
#define DEFAULT_SHOW_DATE true
#define DEFAULT_SHOW_TEMPERATURE true
void storage_init();
bool storage_ready_status();
bool storage_exists();
bool storage_load();
bool storage_save();
void storage_begin_batch();
bool storage_end_batch();
void storage_flush();
void storage_create_defaults();
void storage_reset();
bool storage_factory_reset();
bool storage_delete_config();
bool storage_format();
bool storage_read_json(
    JsonDocument &doc
);
bool storage_write_json(
    JsonDocument &doc
);
bool storage_validate_config();
bool storage_migrate_config(
    JsonDocument &doc
);
bool storage_set_string(
    const char *path,
    String value
);
String storage_get_string(
    const char *path,
    String defaultValue
);
bool storage_set_int(
    const char *path,
    int value
);
int storage_get_int(
    const char *path,
    int defaultValue
);
bool storage_set_float(
    const char *path,
    float value
);
float storage_get_float(
    const char *path,
    float defaultValue
);
bool storage_set_bool(
    const char *path,
    bool value
);
bool storage_get_bool(
    const char *path,
    bool defaultValue
);
bool storage_has_key(
    const char *path
);
bool storage_remove_key(
    const char *path
);
bool storage_set_device_name(
    String name
);
String storage_get_device_name(
    String defaultValue
);
bool storage_set_wifi(
    String ssid,
    String password
);
String storage_get_wifi_ssid(
    String defaultValue
);
String storage_get_wifi_password(
    String defaultValue
);
bool storage_set_wifi_enable(
    bool state
);
bool storage_get_wifi_enable(
    bool defaultValue
);
bool storage_set_wifi_auto_reconnect(
    bool state
);
bool storage_get_wifi_auto_reconnect(
    bool defaultValue
);
bool storage_set_mqtt_enable(
    bool state
);
bool storage_get_mqtt_enable(
    bool defaultValue
);
bool storage_set_mqtt_server(
    String server
);
String storage_get_mqtt_server(
    String defaultValue
);
bool storage_set_mqtt_port(
    int port
);
int storage_get_mqtt_port(
    int defaultValue
);
bool storage_set_mqtt_user(
    String user
);
String storage_get_mqtt_user(
    String defaultValue
);
bool storage_set_mqtt_password(
    String password
);
String storage_get_mqtt_password(
    String defaultValue
);
bool storage_set_mqtt_topic(
    String topic
);
String storage_get_mqtt_topic(
    String defaultValue
);
bool storage_set_location(
    float latitude,
    float longitude
);
float storage_get_latitude(
    float defaultValue
);
float storage_get_longitude(
    float defaultValue
);
bool storage_set_city(
    String city
);
String storage_get_city(
    String defaultValue
);
bool storage_set_country(
    String country
);
String storage_get_country(
    String defaultValue
);
bool storage_set_timezone(
    int timezone
);
int storage_get_timezone(
    int defaultValue
);
bool storage_set_time_format(
    String format
);
String storage_get_time_format(
    String defaultValue
);
bool storage_set_calculation_method(
    String method
);
String storage_get_calculation_method(
    String defaultValue
);
bool storage_set_asr_method(
    String method
);
String storage_get_asr_method(
    String defaultValue
);
bool storage_set_high_latitude_rule(
    String rule
);
String storage_get_high_latitude_rule(
    String defaultValue
);
bool storage_set_fajr_offset(
    int value
);
int storage_get_fajr_offset(
    int defaultValue
);
bool storage_set_dhuhr_offset(
    int value
);
int storage_get_dhuhr_offset(
    int defaultValue
);
bool storage_set_asr_offset(
    int value
);
int storage_get_asr_offset(
    int defaultValue
);
bool storage_set_maghrib_offset(
    int value
);
int storage_get_maghrib_offset(
    int defaultValue
);
bool storage_set_isha_offset(
    int value
);
int storage_get_isha_offset(
    int defaultValue
);
bool storage_set_volume(
    int volume
);
int storage_get_volume(
    int defaultValue
);
bool storage_set_audio_enable(
    bool state
);
bool storage_get_audio_enable(
    bool defaultValue
);
bool storage_set_azan_enable(
    bool state
);
bool storage_get_azan_enable(
    bool defaultValue
);
bool storage_set_azan_folder(
    int folder
);
int storage_get_azan_folder(
    int defaultValue
);
bool storage_set_athan_file(
    int file
);
int storage_get_athan_file(
    int defaultValue
);
bool storage_set_surah_folder(
    int folder
);
int storage_get_surah_folder(
    int defaultValue
);
bool storage_set_surah_file(
    int file
);
int storage_get_surah_file(
    int defaultValue
);
bool storage_set_short_surah_folder(
    int folder
);
int storage_get_short_surah_folder(
    int defaultValue
);
bool storage_set_dua_folder(
    int folder
);
int storage_get_dua_folder(
    int defaultValue
);
bool storage_set_iqama_enable(
    bool state
);
bool storage_get_iqama_enable(
    bool defaultValue
);
bool storage_set_iqama_folder(
    int folder
);
int storage_get_iqama_folder(
    int defaultValue
);
bool storage_set_iqama_file(
    int file
);
int storage_get_iqama_file(
    int defaultValue
);
bool storage_set_iqama_delay(
    int delay
);
int storage_get_iqama_delay(
    int defaultValue
);
bool storage_set_iqama_volume(
    int volume
);
int storage_get_iqama_volume(
    int defaultValue
);
bool storage_set_iqama_fajr_enable(
    bool state
);
bool storage_get_iqama_fajr_enable(
    bool defaultValue
);
bool storage_set_iqama_dhuhr_enable(
    bool state
);
bool storage_get_iqama_dhuhr_enable(
    bool defaultValue
);
bool storage_set_iqama_asr_enable(
    bool state
);
bool storage_get_iqama_asr_enable(
    bool defaultValue
);
bool storage_set_iqama_maghrib_enable(
    bool state
);
bool storage_get_iqama_maghrib_enable(
    bool defaultValue
);
bool storage_set_iqama_isha_enable(
    bool state
);
bool storage_get_iqama_isha_enable(
    bool defaultValue
);
bool storage_set_iqama_fajr_delay(
    int value
);
int storage_get_iqama_fajr_delay(
    int defaultValue
);
bool storage_set_iqama_dhuhr_delay(
    int value
);
int storage_get_iqama_dhuhr_delay(
    int defaultValue
);
bool storage_set_iqama_asr_delay(
    int value
);
int storage_get_iqama_asr_delay(
    int defaultValue
);
bool storage_set_iqama_maghrib_delay(
    int value
);
int storage_get_iqama_maghrib_delay(
    int defaultValue
);
bool storage_set_iqama_isha_delay(
    int value
);
int storage_get_iqama_isha_delay(
    int defaultValue
);
bool storage_set_morning_adhkar_enable(
    bool state
);
bool storage_get_morning_adhkar_enable(
    bool defaultValue
);
bool storage_set_morning_adhkar_folder(
    int value
);
int storage_get_morning_adhkar_folder(
    int defaultValue
);
bool storage_set_morning_adhkar_file(
    int value
);
int storage_get_morning_adhkar_file(
    int defaultValue
);
bool storage_set_morning_adhkar_hour(
    int value
);
int storage_get_morning_adhkar_hour(
    int defaultValue
);
bool storage_set_morning_adhkar_minute(
    int value
);
int storage_get_morning_adhkar_minute(
    int defaultValue
);
bool storage_set_morning_adhkar_volume(
    int value
);
int storage_get_morning_adhkar_volume(
    int defaultValue
);
bool storage_set_morning_adhkar_play_folder(
    bool state
);
bool storage_get_morning_adhkar_play_folder(
    bool defaultValue
);
bool storage_set_evening_adhkar_enable(
    bool state
);
bool storage_get_evening_adhkar_enable(
    bool defaultValue
);
bool storage_set_evening_adhkar_folder(
    int value
);
int storage_get_evening_adhkar_folder(
    int defaultValue
);
bool storage_set_evening_adhkar_file(
    int value
);
int storage_get_evening_adhkar_file(
    int defaultValue
);
bool storage_set_evening_adhkar_hour(
    int value
);
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

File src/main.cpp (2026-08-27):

#include <Arduino.h>
#include <ESP8266WiFi.h>

#include "version.h"
#include "storage.h"
#include "settings.h"

#include "wifi_manager.h"
#include "time_manager.h"
#include "ota_manager.h"

#include "mqtt_manager.h"
#include "command_handler.h"

#include "web_server.h"

#include "dfplayer.h"
#include "display.h"
#include "prayer.h"
#include "hardware.h"
#include "rotary_menu.h"
#include "api_client.h"
#include "event_log.h"


// =================================
// Network Services State
// =================================

static bool networkServicesInitialized = false;


// =================================
// Initialize Network Services
// =================================

static void initialize_network_services()
{
    if (networkServicesInitialized)
    {
        return;
    }

    if (!wifi_connected())
    {
        return;
    }


    Serial.println();
    Serial.println("==============================");
    Serial.println(" Initializing Network Services");
    Serial.println("==============================");


    // ---------------------------------
    // OTA
    // ---------------------------------

    Serial.println("[INIT] OTA");

    OTA.begin();


    // ---------------------------------
    // Time / NTP
    // ---------------------------------

    Serial.println("[INIT] Time");

    time_init();


    // ---------------------------------
    // Check Time
    // ---------------------------------

    if (!time_is_ready())
    {
        Serial.println(
            "[TIME] NTP synchronization failed"
        );

        Serial.println(
            "[TIME] Services will retry later"
        );

        return;
    }


    // ---------------------------------
    // MQTT
    // ---------------------------------

    Serial.println("[INIT] MQTT");

    mqtt_init();


    // ---------------------------------
    // DFPlayer
    // ---------------------------------

    Serial.println("[INIT] DFPlayer");

    dfplayer_init();


    // ---------------------------------
    // Prayer
    // ---------------------------------

    Serial.println("[INIT] Prayer");

    prayer_init();


    // ---------------------------------
    // Display
    // ---------------------------------

    Serial.println("[INIT] Display");

    display_init();

    Serial.printf("[HEAP] After all init: %d\n", ESP.getFreeHeap());


    // ---------------------------------
    // Mark Initialized
    // ---------------------------------

    networkServicesInitialized = true;


    log_event("SYS", "boot", "system", "ok");


    Serial.println();
    Serial.println("==============================");
    Serial.println(" Network Services Ready");
    Serial.println("==============================");

    Serial.println("OTA: READY");
    Serial.println("Time: READY");
    Serial.println("Prayer: READY");
    Serial.println("MQTT: INITIALIZED");
    Serial.println("DFPlayer: INITIALIZED");
    Serial.println("Display: INITIALIZED");

    Serial.println("==============================");
}


// =================================
// Setup
// =================================

void setup()
{
    // ---------------------------------
    // Serial
    // ---------------------------------

    Serial.begin(115200);
    delay(100);

    Serial.println();
    Serial.println();

    Serial.println("==============================");
    Serial.println(" ESP Prayer System");
    Serial.println(" Starting...");
    Serial.println("==============================");


    // ---------------------------------
    // System Information
    // ---------------------------------

    print_version();


    // ---------------------------------
    // Storage
    // ---------------------------------

    Serial.println();
    Serial.println("[INIT] Storage");

    storage_init();


    // ---------------------------------
    // Event Log
    // ---------------------------------

    Serial.println("[INIT] Event Log");

    event_log_init();


    // ---------------------------------
    // Settings
    // ---------------------------------

    Serial.println("[INIT] Settings");

    settings_init();

    Serial.printf("[HEAP] After settings_init: %d\n", ESP.getFreeHeap());


    // ---------------------------------
    // WiFi
    // ---------------------------------

    Serial.println("[INIT] WiFi");

    wifi_init();

    Serial.print("WiFi connected: ");
    Serial.println(
        wifi_connected()
            ? "YES"
            : "NO"
    );

    Serial.print("AP mode: ");
    Serial.println(
        wifi_is_ap_mode()
            ? "YES"
            : "NO"
    );


    // ---------------------------------
    // Web Server
    // ---------------------------------

    Serial.println("[INIT] Web Server");

    web_server_init();


    // ---------------------------------
    // Try Network Services
    // ---------------------------------

    initialize_network_services();


    // ---------------------------------
    // Command Handler
    // ---------------------------------

    Serial.println("[INIT] Command Handler");

    command_init();


    // ---------------------------------
    // Hardware (Rotary / Stop / Buzzer)
    // ---------------------------------

    Serial.println("[INIT] Hardware");

    hardware_init();

    // Play WiFi connected tone after hardware init
    // (startup tone plays first from hardware_init)
    if (wifi_connected())
    {
        buzzer_wifi_connected_tone();
    }


    Serial.println("[INIT] Rotary Menu");

    rotary_menu_init();


    // ---------------------------------
    // System Ready
    // ---------------------------------

    Serial.println();
    Serial.println("==============================");
    Serial.println(" System Ready");
    Serial.println("==============================");


    if (wifi_connected())
    {
        Serial.print("IP Address: ");
        Serial.println(
            WiFi.localIP()
        );

        if (networkServicesInitialized)
        {
            Serial.println("Network Services: READY");
        }
        else
        {
            Serial.println(
                "Network Services: WAITING"
            );
        }
    }
    else
    {
        Serial.println(
            "Network services waiting for WiFi."
        );
    }


    Serial.println("==============================");
    Serial.println();
}


// =================================
// Main Loop
// =================================

void loop()
{
    // ---------------------------------
    // Hardware (Rotary / Stop / Buzzer)
    // ---------------------------------

    hardware_loop();


    // ---------------------------------
    // WiFi
    // ---------------------------------

    wifi_loop();


    // ---------------------------------
    // Detect WiFi Connection
    // ---------------------------------

    if (wifi_connected())
    {
        // ---------------------------------
        // Initialize Services After WiFi
        // ---------------------------------

        initialize_network_services();


        // ---------------------------------
        // OTA
        // ---------------------------------

        if (networkServicesInitialized)
        {
            OTA.handle();
        }


        // ---------------------------------
        // MQTT
        // ---------------------------------

        if (networkServicesInitialized)
        {
            mqtt_loop();
        }


        // ---------------------------------
        // Time
        // ---------------------------------

        if (networkServicesInitialized)
        {
            time_update();
        }
    }


    // ---------------------------------
    // Prayer
    // ---------------------------------

    if (networkServicesInitialized)
    {
        prayer_loop();
    }


    // ---------------------------------
    // Display + Rotary Menu
    // ---------------------------------

    if (networkServicesInitialized)
    {
        rotary_menu_loop();
    }


    // ---------------------------------
    // DFPlayer non-blocking playback
    // ---------------------------------

    dfplayer_loop();


    // ---------------------------------
    // Web Server
    // ---------------------------------

    web_server_loop();


    // ---------------------------------
    // API Diagnostic Test (non-blocking)
    // ---------------------------------

    api_process_test();


    // ---------------------------------
    // Event Log (batch save to LittleFS)
    // ---------------------------------

    event_log_loop();
}

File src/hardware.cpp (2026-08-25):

#include "hardware.h"

#include <Arduino.h>

#include "dfplayer.h"
#include "settings.h"

// =================================================
// Rotary Encoder State
// =================================================

static volatile int8_t rotaryDelta = 0;

static bool lastClkState = false;

static bool lastSwState    = HIGH;

static unsigned long lastSwBounce   = 0;

// =================================================
// Stop Button State
// =================================================

static bool lastStopState = HIGH;

static unsigned long lastStopBounce = 0;

static bool stopHandled = true;

// =================================================
// Button Event State
// =================================================

static unsigned long swPressStart = 0;

static bool swDown = false;

static ButtonEvent swPendingEvent = BTN_NONE;

// =================================================
// Buzzer Legacy State (on/off beep)
// =================================================

static bool buzzerLegacyActive = false;

static bool buzzerPinState = false;

static uint8_t buzzerRepeatCount = 0;

static uint8_t buzzerCurrentRepeat = 0;

static uint16_t buzzerOnTime = 200;

static uint16_t buzzerOffTime = 200;

static unsigned long buzzerLastToggle = 0;

static bool buzzerWaitOff = false;

// =================================================
// Buzzer Tone Sequence State
// =================================================

static bool toneSequenceActive = false;

static const ToneSequence* toneSequencePtr = nullptr;

static uint8_t toneCurrentStep = 0;

static uint8_t toneCurrentRepeat = 0;

static unsigned long toneStepStart = 0;

static bool toneInPause = false;

// =================================================
// Tone Definitions
// =================================================

// 1. Startup: 800->1200->1600->2200
static const ToneStep startupSteps[] = {
    { 800,  100 },
    { 1200, 100 },
    { 1600, 100 },
    { 2200, 250 }
};

// 2. Button Confirm: 1400->(silence)->2000
static const ToneStep confirmSteps[] = {
    { 1400, 100 },
    { 0,    60  },
    { 2000, 180 }
};

// 3. Alarm Classic: 1800<->2400 x20
static const ToneStep alarmClassicSteps[] = {
    { 1800, 180 },
    { 2400, 180 }
};

// 4. Alarm High: 2000<->2600 x30
static const ToneStep alarmHighSteps[] = {
    { 2000, 120 },
    { 2600, 120 }
};

// 5. Warning: 2500->1200 x3
static const ToneStep warningSteps[] = {
    { 2500, 200 },
    { 1200, 200 }
};

// 6. Notification: 7-note melody
static const ToneStep notificationSteps[] = {
    { 1000, 150 },
    { 1500, 150 },
    { 2000, 150 },
    { 2500, 300 },
    { 2000, 150 },
    { 1500, 150 },
    { 1000, 400 }
};

// 7. Error: 2000->800->2000->800 x2
static const ToneStep errorSteps[] = {
    { 2000, 150 },
    { 800,  150 },
    { 2000, 150 },
    { 800,  300 }
};

// 8. WiFi Connected: 1200->1600->2000
static const ToneStep wifiConnectedSteps[] = {
    { 1200, 100 },
    { 1600, 100 },
    { 2000, 200 }
};

// 9. Settings Saved: 1800->2200
static const ToneStep settingsSavedSteps[] = {
    { 1800, 80  },
    { 2200, 150 }
};

// 10. Iqama Reminder: 800->1000->800 x3
static const ToneStep iqamaReminderSteps[] = {
    { 800,  300 },
    { 1000, 300 },
    { 800,  500 }
};

// 11. Button Reject: 600->600 x2
static const ToneStep buttonRejectSteps[] = {
    { 600, 100 },
    { 600, 100 }
};

// 12. Power Off: 2200->1600->1200->800
static const ToneStep powerOffSteps[] = {
    { 2200, 150 },
    { 1600, 150 },
    { 1200, 150 },
    { 800,  300 }
};

// 13. Gentle: 600->800->1000->1200 (slow ascending)
static const ToneStep gentleSteps[] = {
    { 600,  300 },
    { 800,  300 },
    { 1000, 300 },
    { 1200, 400 }
};

// 14. Alarm Clock: 2000x3 fast beeps x5
static const ToneStep alarmClkSteps[] = {
    { 2000, 80  },
    { 0,    80  },
    { 2000, 80  },
    { 0,    80  },
    { 2000, 200 }
};

// 15. Urgent: 3000->1500 fast alternating x10
static const ToneStep urgentSteps[] = {
    { 3000, 100 },
    { 1500, 100 }
};

// 16. Chime: 1000->1500->2000->1500->1000
static const ToneStep chimeSteps[] = {
    { 1000, 150 },
    { 1500, 150 },
    { 2000, 200 },
    { 1500, 150 },
    { 1000, 300 }
};

// =================================================
// Tone Sequence Constants
// =================================================

static const ToneSequence seqStartup = {
    startupSteps, 4, 0, 1
};

static const ToneSequence seqConfirm = {
    confirmSteps, 3, 0, 1
};

static const ToneSequence seqAlarmClassic = {
    alarmClassicSteps, 2, 0, 20
};

static const ToneSequence seqAlarmHigh = {
    alarmHighSteps, 2, 0, 30
};

static const ToneSequence seqWarning = {
    warningSteps, 2, 0, 3
};

static const ToneSequence seqNotification = {
    notificationSteps, 7, 0, 1
};

static const ToneSequence seqError = {
    errorSteps, 4, 0, 2
};

static const ToneSequence seqWifiConnected = {
    wifiConnectedSteps, 3, 0, 1
};
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

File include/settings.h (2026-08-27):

#ifndef SETTINGS_H
#define SETTINGS_H

#include <Arduino.h>


// =================================
// Default Values
// =================================

#define DEVICE_NAME_DEFAULT "ESP-Prayer-System"

#define DEFAULT_CITY "Al Ain"
#define DEFAULT_COUNTRY "UAE"

#define DEFAULT_LATITUDE 24.2075f
#define DEFAULT_LONGITUDE 55.7447f
#define DEFAULT_TIMEZONE 4

#define DEFAULT_VOLUME 1
#define DEFAULT_TIME_FORMAT "24H"

#define DEFAULT_ALARM_TONE_TYPE 0

#define ALARM_TONE_MIN 0
#define ALARM_TONE_MAX 7

#define ALARM_TONE_CLASSIC     0
#define ALARM_TONE_HIGH        1
#define ALARM_TONE_WARNING     2
#define ALARM_TONE_MELODY      3
#define ALARM_TONE_GENTLE      4
#define ALARM_TONE_ALARM_CLK   5
#define ALARM_TONE_URGENT      6
#define ALARM_TONE_CHIME       7

#define DEFAULT_CUSTOM_ALERT_DAYS 127

#define OTA_HOSTNAME "ESP-Prayer-System"

#define MQTT_SERVER "192.168.0.100"
#define MQTT_PORT 1883
#define MQTT_TOPIC "ESP-Prayer-System"

#define DEFAULT_PRAYER_SOURCE "local"
#define DEFAULT_CALCULATION_METHOD "UmmAlQura"
#define DEFAULT_ASR_METHOD "Shafii"
#define DEFAULT_HIGH_LATITUDE_RULE "AngleBased"

// =================================
// Prayer Offsets
// =================================

#define DEFAULT_FAJR_OFFSET 0
#define DEFAULT_DHUHR_OFFSET 0
#define DEFAULT_ASR_OFFSET 0
#define DEFAULT_MAGHRIB_OFFSET 0
#define DEFAULT_ISHA_OFFSET 0

// =================================
// Display
// =================================

#define DEFAULT_BRIGHTNESS 100
#define DEFAULT_SHOW_DATE true
#define DEFAULT_SHOW_TEMPERATURE true




// =================================
// Audio Limits
// =================================

#define AUDIO_VOLUME_MIN 0
#define AUDIO_VOLUME_MAX 30

#define AUDIO_FOLDER_MIN 1
#define AUDIO_FOLDER_MAX 99

#define AUDIO_FILE_MIN 1
#define AUDIO_FILE_MAX 255

#define IQAMA_DELAY_MIN 0
#define IQAMA_DELAY_MAX 60



// =================================
// System Settings Structure
// =================================

#define SET_STR_DEVICE_NAME   33
#define SET_STR_WIFI_SSID     33
#define SET_STR_WIFI_PASS     65
#define SET_STR_MQTT_SERVER   33
#define SET_STR_MQTT_USER     33
#define SET_STR_MQTT_PASS     33
#define SET_STR_MQTT_TOPIC    65
#define SET_STR_OTA_HOST      33
#define SET_STR_OTA_PASS      33
#define SET_STR_CITY          33
#define SET_STR_COUNTRY       17
#define SET_STR_PRAYER_SRC    9
#define SET_STR_CALC_METHOD   17
#define SET_STR_ASR_METHOD    9
#define SET_STR_HI_LAT_RULE   17
#define SET_STR_TIME_FMT      5
#define SET_STR_QURAN_SEL     33

struct SystemSettings
{

    // =========================
    // Device
    // =========================

    char deviceName[SET_STR_DEVICE_NAME];



    // =========================
    // WiFi
    // =========================

    bool wifiEnable;

    char wifiSSID[SET_STR_WIFI_SSID];

    char wifiPassword[SET_STR_WIFI_PASS];

    bool wifiAutoReconnect;



    // =========================
    // MQTT
    // =========================

    bool mqttEnable;

    char mqttServer[SET_STR_MQTT_SERVER];

    int mqttPort;

    char mqttUser[SET_STR_MQTT_USER];

    char mqttPassword[SET_STR_MQTT_PASS];

    char mqttTopic[SET_STR_MQTT_TOPIC];



    // =========================
    // OTA
    // =========================

    bool otaEnable;

    char otaHostname[SET_STR_OTA_HOST];

    char otaPassword[SET_STR_OTA_PASS];



    // =========================
    // Location
    // =========================

    char city[SET_STR_CITY];

    char country[SET_STR_COUNTRY];

    float latitude;

    float longitude;

    int timezone;



    // =========================
    // Prayer
    // =========================

    char prayerSource[SET_STR_PRAYER_SRC];

    char calculationMethod[SET_STR_CALC_METHOD];

    char asrMethod[SET_STR_ASR_METHOD];

    char highLatitudeRule[SET_STR_HI_LAT_RULE];

    char timeFormat[SET_STR_TIME_FMT];


    int fajrOffset;

    int dhuhrOffset;

    int asrOffset;

    int maghribOffset;

    int ishaOffset;



// =========================
// Audio
// =========================

bool audioEnable;

bool azanEnable;

int volume;

bool lowVolumeEnable;

int lowVolumeLevel;

uint8_t alarmToneType;


// =========================
// Custom Alert
// =========================

bool customAlertEnable;

int customAlertSource;  // 0=Buzzer, 1=File

int customAlertHour;

int customAlertMinute;

int customAlertDays;    // bitmask: bit0=Sun ... bit6=Sat

int customAlertRepeat;  // 0=off, 1-4

int customAlertInterval; // minutes between repeats (1-60)

int customAlertFile;    // DFPlayer file (1-11)

int customAlertVolume;  // DFPlayer volume (0-30)


// =========================
// Azan
// =========================

int azanDevice;   // 0=DFPlayer, 1=Buzzer

int azanBuzzerTone; // ALARM_TONE_*

int azanFolder;

int azanFile;


// =========================
// Iqama
// =========================

bool iqamaEnable;

int iqamaDevice;  // 0=DFPlayer, 1=Buzzer

int iqamaBuzzerTone; // ALARM_TONE_*

int iqamaFolder;

int iqamaFile;

int iqamaDelayMinutes;

int iqamaVolume;

bool iqamaPrayerEnable[6];

int iqamaPrayerDelay[6];


// =========================
// Quran
// =========================

bool quranEnable;

int quranHour;

int quranMinute;

int quranVolume;

char quranSelected[SET_STR_QURAN_SEL];

int quranFolder;

int quranFile;


// Structured scheduled Quran items
struct QuranItemSettings
{
    bool enable;
    int hour;
    int minute;
    int volume;
    int folder;
    int file;
};

QuranItemSettings quranBaqarah;
QuranItemSettings quranBaqarahLast;
QuranItemSettings quranAyatKursi;
QuranItemSettings quranMaryam;


// =========================
// Morning Adhkar
// =========================

bool morningAdhkarEnable;

int morningAdhkarFolder;

int morningAdhkarFile;

int morningAdhkarHour;

int morningAdhkarMinute;

int morningAdhkarVolume;

bool morningAdhkarPlayFolder;


// =========================
// Evening Adhkar
// =========================

bool eveningAdhkarEnable;

int eveningAdhkarFolder;

int eveningAdhkarFile;

int eveningAdhkarHour;

int eveningAdhkarMinute;

int eveningAdhkarVolume;

bool eveningAdhkarPlayFolder;


// =========================
// Kahf
// =========================

bool kahfEnable;

int kahfFolder;

int kahfFile;

int kahfHour;

int kahfMinute;

int kahfVolume;

bool kahfPlayFolder;


// =========================
// Short Surah
// =========================

int shortSurahFolder;


// =========================
// Dua
// =========================

int duaFolder;


// =========================
// Eid Takbeerat
// =========================

bool eidTakbeeratEnable;

int eidTakbeeratVolume;


// =========================
// Ruqyah
// =========================

int ruqyahFolder;

int ruqyahFile;

int ruqyahVolume;


// =========================
// Dhikr Repeat
// =========================

bool dhikrRepeatEnable;

int dhikrRepeatInterval; // 1-60 minutes

int dhikrRepeatVolume;


    // =========================
    // Display
    // =========================

    bool displayEnable;

    int brightness;

    bool showDate;

    bool showTemperature;

    int eventDisplayDuration;  // seconds, how long event status shows on LCD

};



// =================================
// Global Object
// =================================

extern SystemSettings settings;



// =================================
// Initialization
// =================================

void settings_init();

void settings_load();

void settings_save();

void settings_reset();



// =================================
// Getters
// =================================


const char* get_device_name();


const char* get_time_format();


int get_volume();


bool wifi_is_enabled();


bool mqtt_is_enabled();


bool audio_is_enabled();



const char* get_city();


const char* get_country();


float get_latitude();


float get_longitude();


int get_timezone();



const char* get_calculation_method();


const char* get_asr_method();


// =================================
// Runtime Update
// =================================


void settings_apply();

#endif

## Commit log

2026-08-02 Fix prayer settings storage and time format handling
    [dfplayer.cpp, main.cpp]
2026-08-05 Backup before WiFi Manager redesign
    [command_handler.cpp, dfplayer.cpp, display.cpp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]
2026-08-06 Add LCD display integration and redesign AP WiFi setup page
    [dfplayer.cpp, main.cpp, prayer.cpp]
2026-08-19 Add non-blocking buzzer tone system with 12 tones and alarm type selection
    - Add ToneStep/ToneSequence structs and 12 non-blocking tone definitions
    - Add buzzer_play_alarm() with Classic/High/Warning/Melody options
    - Add alarm tone type selector in web UI audio settings
    - Fix WiFi connected tone killed by startup tone (reorder in main.cpp)
    - Fix alarmToneType not saved from inline script in audio.html
    - Add buzzer_settings_saved_tone() after successful settings save
    - Add buzzer_error_tone() on DFPlayer init failure and storage errors
    - Add buzzer_iqama_reminder_tone() before iqama audio
    - Add buzzer_power_off_tone() before ESP restart
    - Change BUZZER_PIN from D5 to D3 (GPIO0)
    [command_handler.cpp, dfplayer.cpp, display.cpp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]
2026-08-19 Add custom alert feature + 4 new alarm tones (v2)
    - Add 4 new buzzer tones: Gentle(4), AlarmClock(5), Urgent(6), Chime(7)
    - Add custom alert with 8 settings: enable, source(B/F), hour, minute, days, repeat(0-4), interval(1-60min), file(1-11), volume
    - Custom alert scheduling in prayer_loop with repeat support
    - Config version migration V3->V4 for new fields
    - Web UI: custom alert section with days checkboxes, repeat dropdown, B/F source toggle, test buttons
    - Test endpoint: /api/test/custom-alert-file for DFPlayer file preview
    - Web API: full GET/POST for all custom alert fields
    [hardware.cpp, prayer.cpp, settings.cpp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]
2026-08-19 Add rotary encoder menu system with 4 LCD modes (v1.6.0)
    - New files: rotary_menu.h/cpp with state machine (CLOCK/MENU/PRAYERS/VOLUME/BRIGHTNESS)
    - Long/short press detection (>500ms threshold) on rotary button
    - MODE_CLOCK: normal clock display with next prayer countdown
    - MODE_MENU: navigate 3 menu items (Prayer Times, Volume, Brightness)
    - MODE_PRAYERS: browse 6 prayers with name, time, next prayer marker
    - MODE_VOLUME: adjust 0-30 with beep feedback + immediate save
    - MODE_BRIGHTNESS: toggle backlight on/off + immediate save
    - Snooze: any press during buzzer stops alarm (highest priority)
    - ALARM display: shows ALARM! + time on LCD
    - New display functions: menu_items, menu_prayers, menu_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
    [display.cpp, hardware.cpp, hardware.h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]
2026-08-20 Fix rotary encoder direction - remove D8 pull-down dependency
    [hardware.cpp]
2026-08-20 Unified settings page, rotary volume control, LCD time format fix (v1.7.0)
    - Consolidated settings.html with 6 tabs (Prayer, Alert, Adhkar, Quran, Network, System)
    - Per-tab save buttons with individual collect/save functions
    - Rotary encoder: volume up/down in clock mode, short press mute, long press menu
    - LCD: removed AM/PM from 12H format display
    - Prayer times: removed AM/PM suffix from 12H format
    - Developer info added to system tab (Badi Electronic)
    - Removed old separate HTML pages (audio, prayer, network, system)
    - Cleaned up OLD backup files
    - PCB documentation added
    [ESP-Prayer-System.fzz, netlist.csv]
2026-08-25 Quran scheduled playback, folder play persistence, default settings reset (v1.9.3)
    [dfplayer.cpp, display.cpp, main.cpp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]
2026-08-25 Smart dhikr repeat, dhikr counter, ruqyah, eid takbeerat, adhkar player, updated SD file lists, fixed defaults (v1.10.0)
    [dfplayer.cpp, prayer.cpp, settings.cpp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]
2026-08-25 UAE prayer calculation, iqama per-prayer delays, local Hijri date, ruqyah/iqama audio, disable HW stop button (v1.11.0)
2026-08-27 Fix scheduled features not re-triggering after settings change; add event log module; unify web assets (v1.11.0)
    [display.cpp, event_log.cpp, main.cpp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]
2026-08-27 Fix JSON response corruption from shared static output buffer in send_json (v1.11.1)
    [web_server.cpp]
2026-08-27 Fix OOM crash: reduce heap pressure and serialize settings-page loads (v1.11.2)
    [web_server.cpp]
2026-08-27 Fix JSON corruption race: use per-request output buffer in send_json (v1.11.3)
    [web_server.cpp]
2026-08-27 Free config RAM cache after settings_load to reduce heap pressure (v1.11.4)
2026-08-27 Default all volumes to 1 and all scheduled features disabled; fix 12/24H persist on load (v16 frontend)
    [storage.cpp, storage.h, web_server.cpp]
2026-08-28 Fix azan/iqama test buttons to respect buzzer device setting (v1.11.5)
    [web_server.cpp]
